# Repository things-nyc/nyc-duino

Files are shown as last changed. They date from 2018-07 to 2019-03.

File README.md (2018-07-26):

# nyc-duino

A simple demo board for the TTN NYC Hardware Office Hours!

## Soldering (optional)

Simple introduction to soldering by attaching the DHT11/22 and a 10k thru-hole pullup resistor. Male or female header can also be added to support Arduino shields.

## Arduino

### Installing

```
https://www.arduino.cc/en/Main/Software
```

### Libraries Needed

Sketch -> Include Library -> Manage Libraries

* Adafruit Unified Sensor - by Adafruit
* DHT sensor library - by Adafruit
* TheThingsNetwork - by The Things Network
* CayenneLPP - by The Things Network

## The Things Network

The Things Network is our LoRaWAN network server.

### Create Account

### Create Application

### Add Cayenne Integration

Also choose Cayenne LPP from Payload Formats tab.

### Add Device

Upload DeviceInfo sketch from TheThingsNetwork library to get DevEUI.

## Firmware

Download nycDuino-demo.ino from this repo.

Use the AppEUI and AppKey from TTN dashboard to personalize the Arduino sketch on lines 6 and 7.

Tools -> Board -> Arduino Leonardo

Upload.

## Cayenne

### Create Account

### Add Device

LoRa -> The Things Network -> Cayenne LPP

## Bonus Round

* Don't use delay() to time transmissions
* Use downlink to set onboard LED state
* Lower power by using sleep and idle

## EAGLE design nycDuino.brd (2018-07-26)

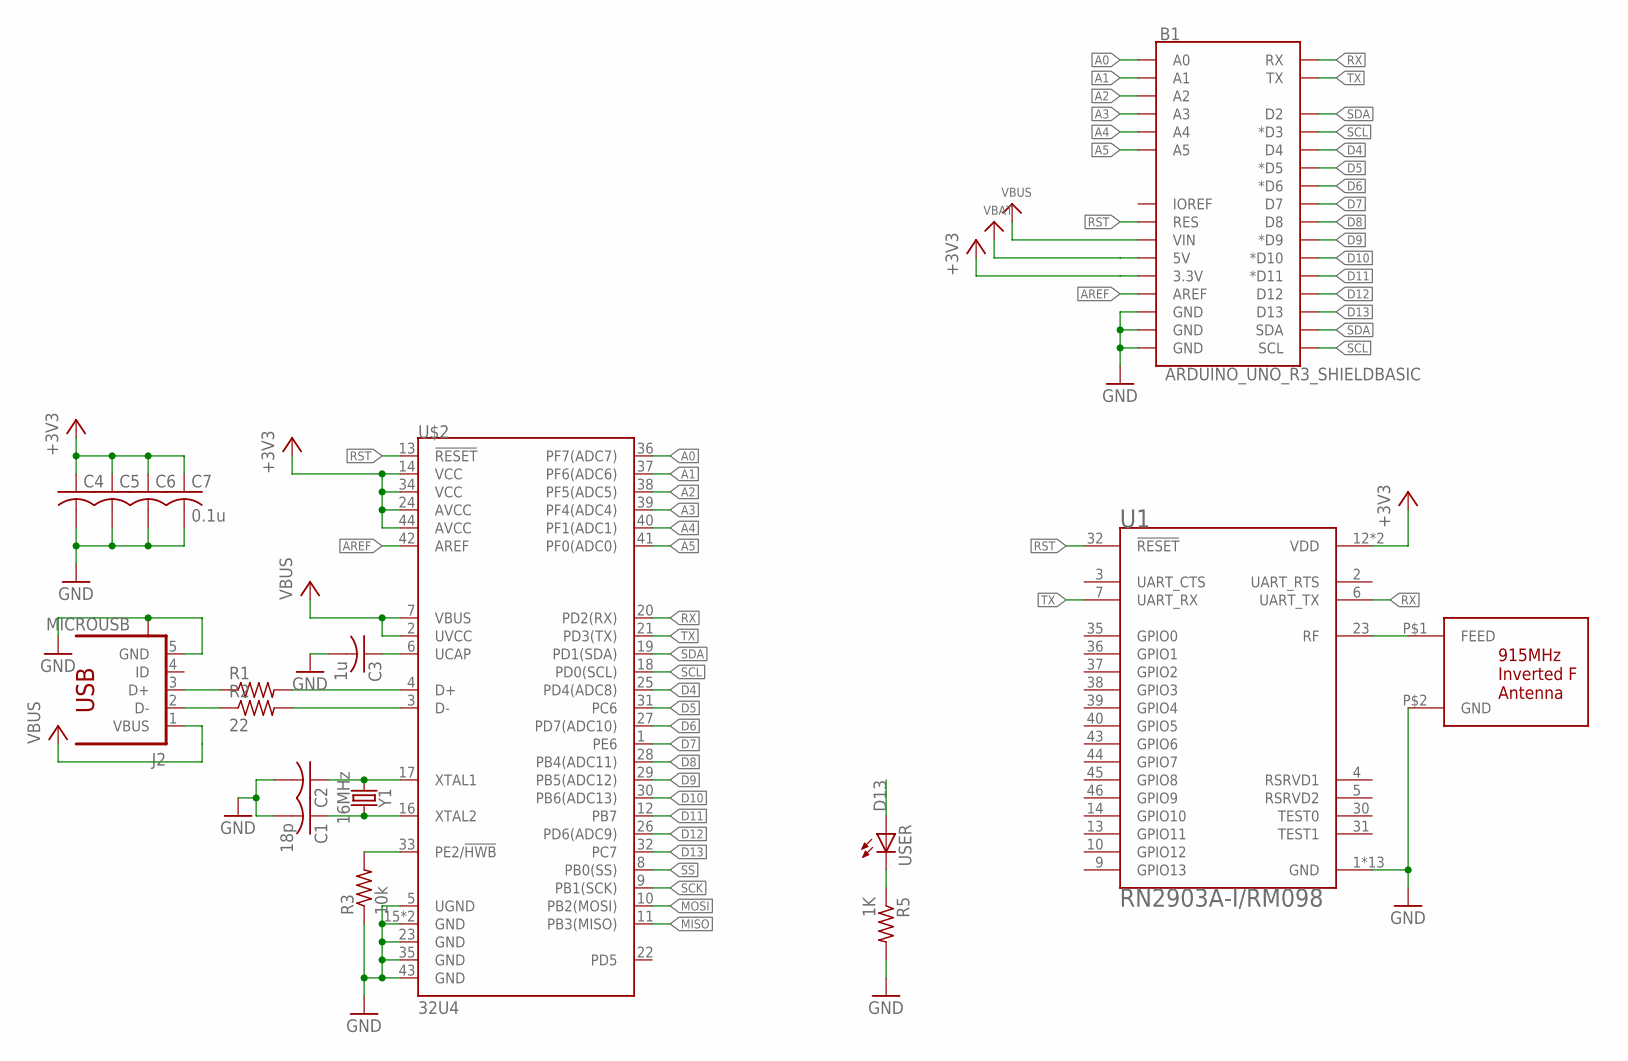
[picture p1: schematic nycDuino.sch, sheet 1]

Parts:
B1: ARDUINO_UNO_R3_SHIELDBASIC; UNO_R3_SHIELD
C1: 18p; C0603
C2, C4, C5, C6: C-USC0603; C0603
C3: 1u; C0603
C7: 0.1u; C0603
J2: MICROUSB; 10118192-0001LF
R1: R-US_R0603; R0603
R2: 22; R0603
R3: 10k; R0603
R5: 1K; R0603
U1: RN2903A-I/RM098; XCVR_RN2903A-I/RM098
U$1: 915MHZ; 915MHZ-F-NOMATCH
U$2: 32U4; QFN-44
USER: LEDCHIP-LED0603; CHIP-LED0603
Y1: 16MHz; CRYSTAL-SMD-5X3.2-4PAD

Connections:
+3V3: B1.3.3V, C4.1, C5.1, C6.1, C7.1, U1.12 (VDD), U1.34 (VDD), U$2.14 (VCC), U$2.24 (AVCC), U$2.34 (VCC), U$2.44 (AVCC); also elsewhere on the board
A0: B1.A0, U$2.36 (PF7(ADC7))
A1: B1.A1, U$2.37 (PF6(ADC6))
A2: B1.A2, U$2.38 (PF5(ADC5))
A3: B1.A3, U$2.39 (PF4(ADC4))
A4: B1.A4, U$2.40 (PF1(ADC1))
A5: B1.A5, U$2.41 (PF0(ADC0))
AREF: B1.AREF, U$2.42 (AREF); also elsewhere on the board
D4: B1.D4, U$2.25 (PD4(ADC8)); also elsewhere on the board
D5: B1.D5 (*D5), U$2.31 (PC6)
D6: B1.D6 (*D6), U$2.27 (PD7(ADC10))
D7: B1.D7, U$2.1 (PE6)
D8: B1.D8, U$2.28 (PB4(ADC11))
D9: B1.D9 (*D9), U$2.29 (PB5(ADC12))
D10: B1.D10 (*D10), U$2.30 (PB6(ADC13))
D11: B1.D11 (*D11), U$2.12 (PB7)
D12: B1.D12, U$2.26 (PD6(ADC9))
D13: B1.D13, U$2.32 (PC7), USER.A
GND: B1.GND@0 (GND), B1.GND@1 (GND), B1.GND@2 (GND), C1.2, C2.2, C3.2, C4.2, C5.2, C6.2, C7.2, J2.5 (GND), J2.M1 (S), J2.M2 (S), J2.S1 (S), J2.S2 (S), J2.S3 (S), J2.S4 (S), R3.1, R5.2, U1.1 (GND), U1.8 (GND), U1.11 (GND), U1.20 (GND), U1.21 (GND), U1.22 (GND), U1.24 (GND), U1.26 (GND), U1.27 (GND), U1.28 (GND), U1.33 (GND), U1.41 (GND), U1.47 (GND), U$1.P$2 (GND), U$2.5 (UGND), U$2.15 (GND), U$2.23 (GND), U$2.35 (GND), U$2.43 (GND), U$2.45 (GND); also elsewhere on the board
MISO: U$2.11 (PB3(MISO)); also elsewhere on the board
MOSI: U$2.10 (PB2(MOSI)); also elsewhere on the board
unnamed: U1.23 (RF), U$1.P$1 (FEED)
unnamed: J2.3 (D+), R1.1
unnamed: J2.2 (D-), R2.1
unnamed: R1.2, U$2.4 (D+)
unnamed: R2.2, U$2.3 (D-)
unnamed: C2.1, U$2.17 (XTAL1), Y1.1
unnamed: C1.1, U$2.16 (XTAL2), Y1.3 (2)
unnamed: C3.1, U$2.6 (UCAP)
unnamed: R3.2, U$2.33 (PE2/!HWB)
unnamed: R5.1, USER.C
RST: B1.RES, U1.32 (!RESET), U$2.13 (!RESET); also elsewhere on the board
RX: B1.RX, U1.6 (UART_TX), U$2.20 (PD2(RX))
SCK: U$2.9 (PB1(SCK)); also elsewhere on the board
SCL: B1.D3 (*D3), B1.SCL, U$2.18 (PD0(SCL))
SDA: B1.D2, B1.SDA, U$2.19 (PD1(SDA))
SS: U$2.8 (PB0(SS))
TX: B1.TX, U1.7 (UART_RX), U$2.21 (PD3(TX))
VBAT: B1.5V; also elsewhere on the board
VBUS: B1.VIN, J2.1 (VBUS), U$2.2 (UVCC), U$2.7 (VBUS); also elsewhere on the board

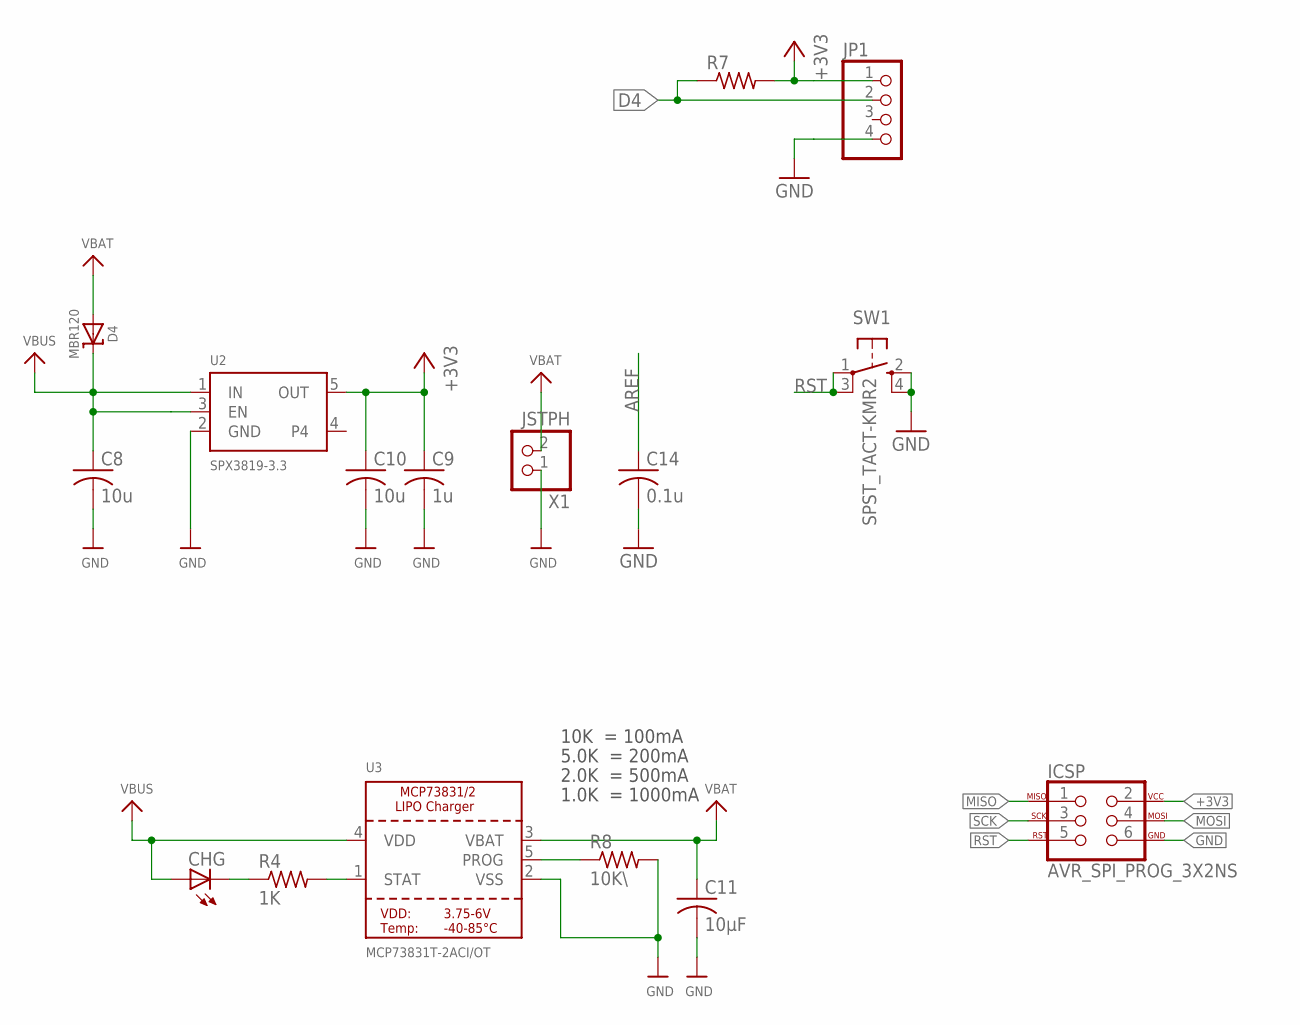
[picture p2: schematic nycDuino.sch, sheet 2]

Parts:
C8, C10: 10u; C0603
C9: 1u; C0603
C11: 10µF; C0603
C14: 0.1u; C0603
CHG: LEDCHIP-LED0603; CHIP-LED0603
D4: MBR120; SOD-123
ICSP: AVR_SPI_PROG_3X2NS; 2X3-NS
JP1: PINHD-1X4; 1X04
R4: 1K; R0603
R7: R-US_0207/7; 0207/7
R8: 10K\; R0603
SW1: SPST_TACT-KMR2; KMR2
U2: SPX3819-3.3; SOT23-5
U3: MCP73831T-2ACI/OT; SOT23-5
X1: JSTPH; JSTPH2

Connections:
+3V3: C9.1, C10.1, ICSP.2, JP1.1, R7.2, U2.5 (OUT); also elsewhere on the board
AREF: C14.1; also elsewhere on the board
D4: JP1.2, R7.1; also elsewhere on the board
GND: C8.2, C9.2, C10.2, C11.2, C14.2, ICSP.6, JP1.4, R8.2, SW1.2 (S), SW1.4 (S1), U2.2 (GND), U3.2 (VSS), X1.1; also elsewhere on the board
MISO: ICSP.1; also elsewhere on the board
MOSI: ICSP.4; also elsewhere on the board
unnamed: CHG.C, R4.1
unnamed: R4.2, U3.1 (STAT)
unnamed: R8.1, U3.5 (PROG)
RST: ICSP.5, SW1.1, SW1.3 (P1); also elsewhere on the board
SCK: ICSP.3; also elsewhere on the board
VBAT: C11.1, D4.A, U3.3 (VBAT), X1.2; also elsewhere on the board
VBUS: C8.1, CHG.A, D4.C, U2.1 (IN), U2.3 (EN), U3.4 (VDD); also elsewhere on the board

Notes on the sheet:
10K = 100mA
5.0K = 200mA
2.0K = 500mA
1.0K = 1000mA

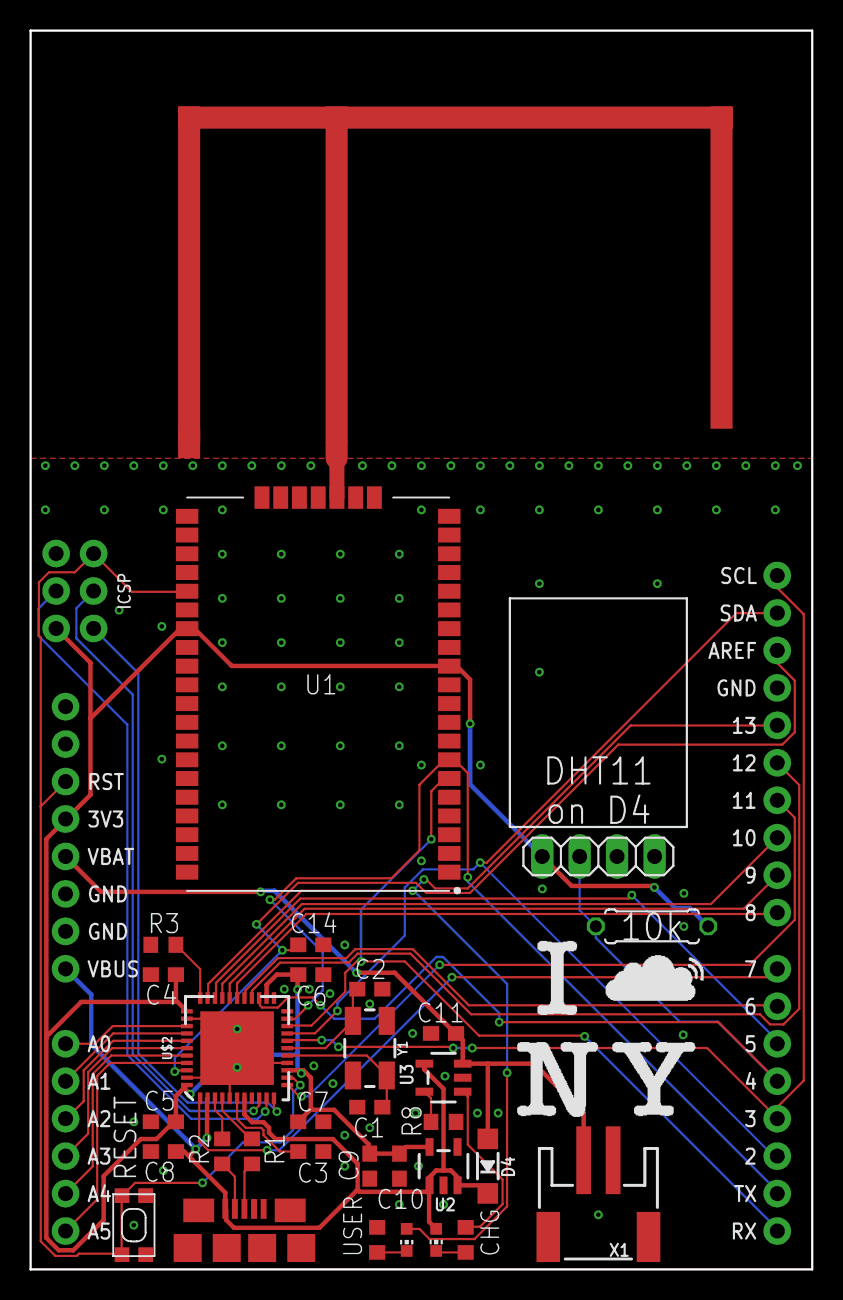
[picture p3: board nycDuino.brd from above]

Board: 2 copper layers, 53.0 x 84.0 mm, 34 parts (0 on the bottom side), 42 nets.

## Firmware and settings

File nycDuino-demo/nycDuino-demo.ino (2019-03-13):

#include <TheThingsNetwork.h>
#include <CayenneLPP.h>
#include <DHT.h>

// Set your AppEUI and AppKey
const char *appEui = "70B3D57ED00117CD";
const char *appKey = "D43209B0B6D943006D9FD0A80FB343D7";

#define loraSerial Serial1
#define debugSerial Serial

// Replace REPLACE_ME with TTN_FP_EU868 or TTN_FP_US915
#define freqPlan TTN_FP_US915

#define DHTPIN 4
#define LEDPIN 13

//Choose your DHT sensor moddel
//#define DHTTYPE DHT11
//#define DHTTYPE DHT21
#define DHTTYPE DHT22

DHT dht(DHTPIN, DHTTYPE);

TheThingsNetwork ttn(loraSerial, debugSerial, freqPlan);

CayenneLPP lpp(51);

static int vccRead()
{
  analogRead(0);                // achieves 90% of ADC setup
  ADMUX = 0b01011110;           // set mux to bandgap input, AVcc ref
  
  delayMicroseconds(250);       // give time for bandgap to settle
  
  ADCSRA |= (1 << ADSC);        // start conversion
  while (ADCSRA & (1 << ADSC)); // wait for conversion to finish

  int x = ADC;
  return (1100L * 1023) / x;    // bandgap is 1100mV nom.
}

void setup()
{
  // Initialize LED and turn it off
  pinMode(LEDPIN, OUTPUT);
  digitalWrite(LEDPIN, LOW);
  
  loraSerial.begin(57600);
  debugSerial.begin(9600);

  // Wait a maximum of 10s for Serial Monitor
  while (!debugSerial && millis() < 10000);

  Serial.println("-- STATUS --");
  ttn.showStatus();

  Serial.println("-- JOIN --");
  ttn.join(appEui, appKey);

  dht.begin();
}

void loop()
{
  Serial.println("-- LOOP --");
  
  // Reading temperature or humidity takes about 250 milliseconds!
  // Sensor readings may also be up to 2 seconds 'old' (its a very slow sensor)
  float h = dht.readHumidity();
  // Read temperature as Celsius (Fahrenheit = true)
  float t = dht.readTemperature();

  // Check if any reads failed and exit early (to try again)
  if (isnan(h) || isnan(t)) {
    Serial.println("Failed to read from DHT sensor!");
    delay(1000);
    return;
  }

  // Read VCC of 32u4, output of 3.3V LDO but can drop when battery is < 3.4V
  int v = vccRead();

  Serial.print("Humidity: ");
  Serial.print(h);
  Serial.print(" %\t");
  Serial.print("Temperature: ");
  Serial.print(t);
  Serial.print(" *C\t");
  Serial.print("VCC: ");
  Serial.print(v);
  Serial.println(" mV");

  // Prepare Cayenne LPP
  lpp.reset();
  lpp.addTemperature(1, t);
  lpp.addRelativeHumidity(2, h);
  lpp.addAnalogInput(3, float(v)/1000);

  // Send it off
  digitalWrite(LEDPIN, HIGH);
  ttn.sendBytes(lpp.getBuffer(), lpp.getSize());
  digitalWrite(LEDPIN, LOW);

  // Wait 20 seconds between transmissions
  delay(20000);
}

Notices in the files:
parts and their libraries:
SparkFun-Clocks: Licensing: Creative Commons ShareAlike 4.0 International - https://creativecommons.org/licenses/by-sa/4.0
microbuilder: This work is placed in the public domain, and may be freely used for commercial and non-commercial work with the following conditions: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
